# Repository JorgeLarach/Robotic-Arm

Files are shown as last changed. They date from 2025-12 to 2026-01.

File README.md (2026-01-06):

# Robot Arm
Welcome to the readme and devlog for my Robot Arm project! This was about a month long project, done entirely in December 2025. Here you will find the code, pictures, and all the documentation you might need for this personal project. It is a 4-axis robotic arm with a gripper, controlled by an STM32 Nucleo-F401RE microcontroller, a PCA9685 servo driver, and a breadboard power supply module I had laying around. You can find a video of this thing working in the Documentation/Pictures folder. Though I'm leaving this project for now, I do plan on coming back and implementing inverse kinematics control. If you have any questions or need to get in touch, feel free to contact me at jorgelarachesp@gmail.com.

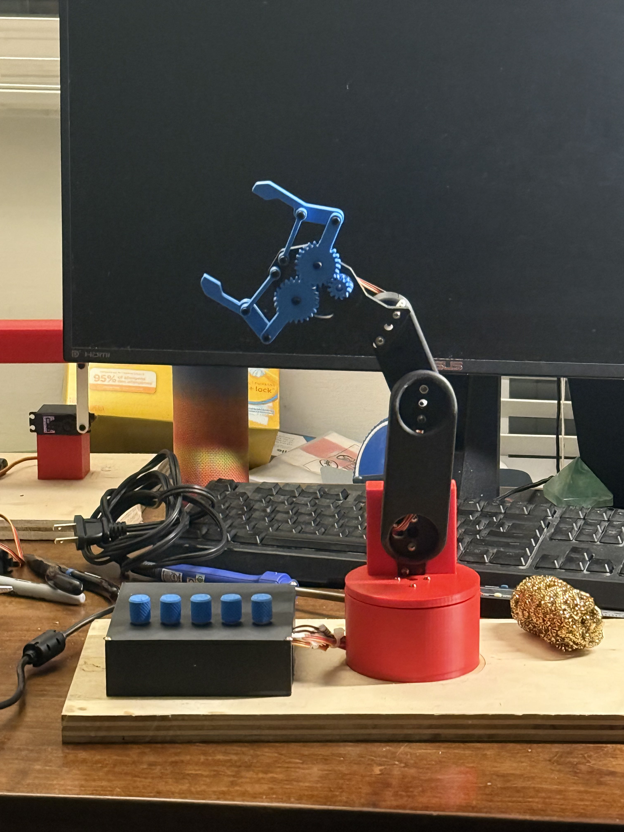
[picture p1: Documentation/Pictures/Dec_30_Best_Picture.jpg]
December 30th best picture

## _Devlog_
### _1/6/2026_:
After I finished the design portion of the robot, I had to come up with a layout and design of the electronics box. I sketched it out on paper, and my original idea was for it to contain:
* the power supply module,
* the STM32 MCU,
* a solder breadboard to supply voltage to the potentiometers, and
* the PCA9685 module.

It wasn't until I modeled it up and printed it that I realized the potentiometers didn't need the breadboard to supply 3.3V and GND to each one, I could just connect the first one to the last 3.3V output on the power supply and daisy chain jumper wires to each subsequent one. I prototyped it out on a solderless breadboard and it worked, so I got to soldering. It was never my strong suit, and I did make a few janky connections that snapped off and had to solder back on later, but it worked! I attached each potentiometer to the lid with some provided nuts and connected their signal wires to the ADC pins on the Nucleo. Unfortunately, this means that you can't remove the lid without disconnecting the signal wires, but I don't mind, since I know exactly where they go. Also there's a big empty space in the box where the solder breadboard would have gone but that's ok. I will admit I made some pretty heinous mistakes with the electronics box design, but its nothing some filing and cutting couldn't fix. 

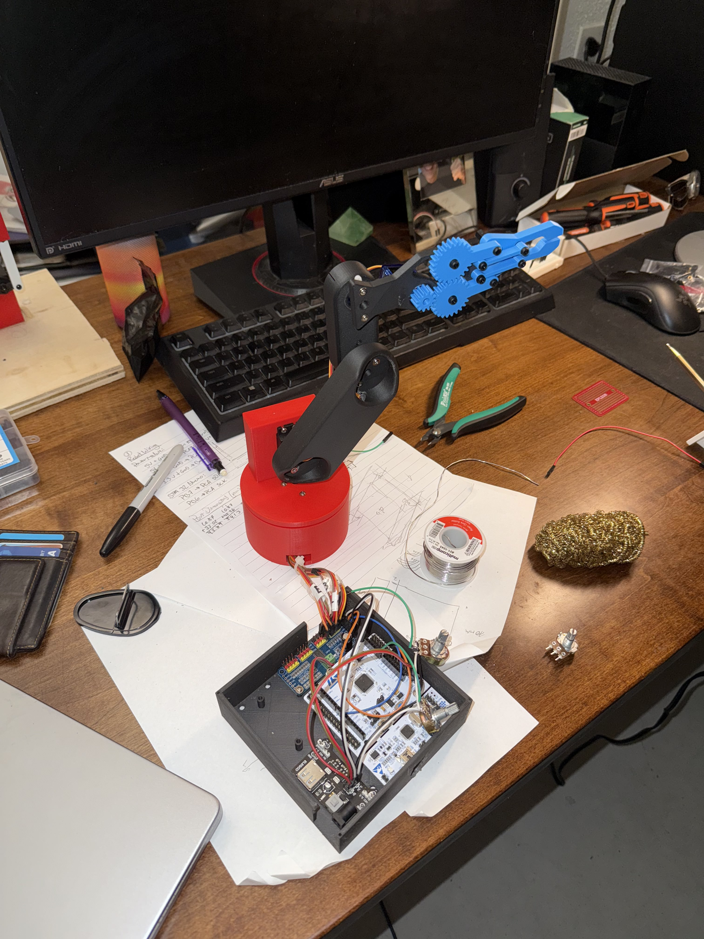
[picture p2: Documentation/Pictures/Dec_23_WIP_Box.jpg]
December 23rd WIP electronics box


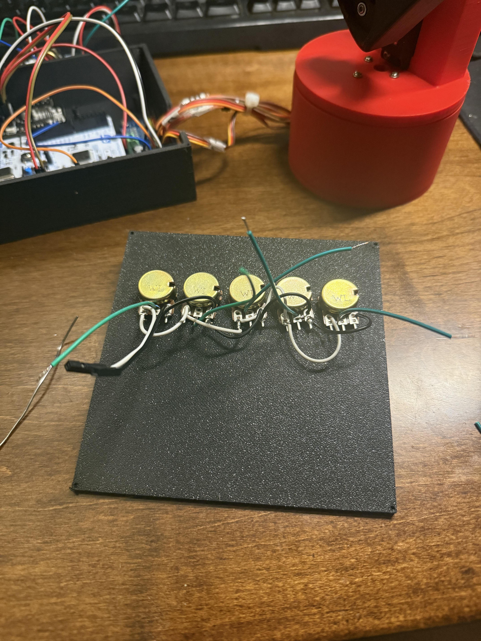
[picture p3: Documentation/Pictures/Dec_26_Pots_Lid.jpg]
December 26th pots on lid


Another big challenge I faced AFTER designing and making the robot was handling multichannel ADC. This completely blindsided me, as I was operating under the understanding that, if it works and its easy with one potentiometer, it'll be easy with more than one. I was dead wrong. This was a much deeper rabbit hole than I ever expected. I'll spare you the gory details, but I ended up using continuously converted DMA accessed ADC values to an ADC array. You can check out the MX_ADC1_Init function in main.c to see more. Once I had that working, I was done with the project on December 30th!
### _12/20/2025_:
The design portion of the project is almost done. I spent a lot of time on Fusion designing and modeling parts, and I was finally able to assemble a working robotic arm today. I used [this](https://www.youtube.com/watch?v=MkABKJTZjVg "Arm reference video") video as a visual reference for the general structure and assembly for my arm, though I included a fifth servo at the tip of the forearm to control the claw angle. I modeled up a claw in Fusion using [this](https://www.youtube.com/watch?v=ZmckF8zYbp0&t=2116s "Fusion claw tutorial") tutorial and modified part of it to fit my arm. All STLs are now included in this repository. The potentiometer and breadboard in the image below are only there for debugging reasons, they won't be there in the final build.

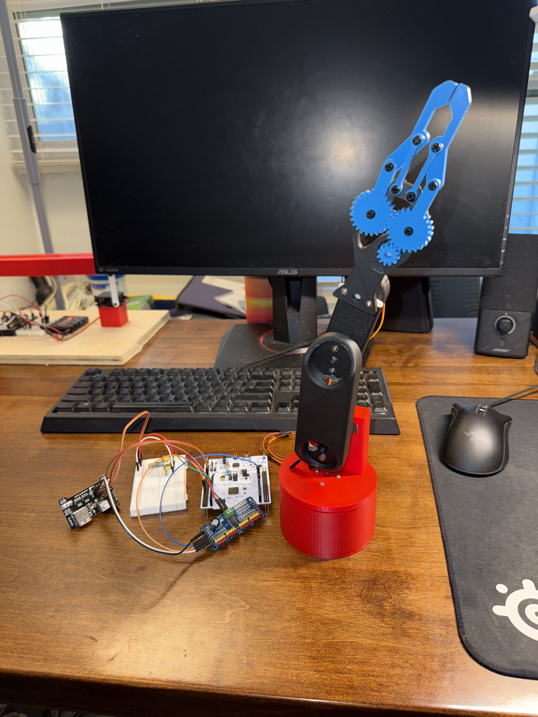
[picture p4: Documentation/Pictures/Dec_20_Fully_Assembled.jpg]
December 20th Fully Assembled


There are five servos: 
* MG996R base servo (provides rotation)
* MG996R lid servo (connects to the arm)
* 2 MG90 forearm servos (one connects to arm, other to control the angle of the claw)
* MG90 claw servo (controls claw mechanism)

Next, I will disassemble the five main pieces of the arm (base, lid, arm, forearm, claw) and individually center each servo at 90 degrees, so there is equal amount of movement on either side available from the centered position. After that, I'll connect extension jumper cables to each MG90 servo (the base and lid servo's wires can reach the PCA9685 no problem) and label each end to their respective servo's funcion. I'll also make an attempt to hide the servo wires as best I can; I included some cable holes in the design but I'm not sure whether they'll actually be all that helpful. After that, I have three more tasks to tackle:
* Build enclosure for electronics (breadboard power supply circuit, MCU, PCA9685)
* Start programming an inverse kinematics driver
* Start designing a smaller, potentiometer driven controller arm (alternative would be to put five potentiometers in the electronics enclosure to control each servo individually)

Below are some pictures of the design process from this past week:

December 17: Working base and lid
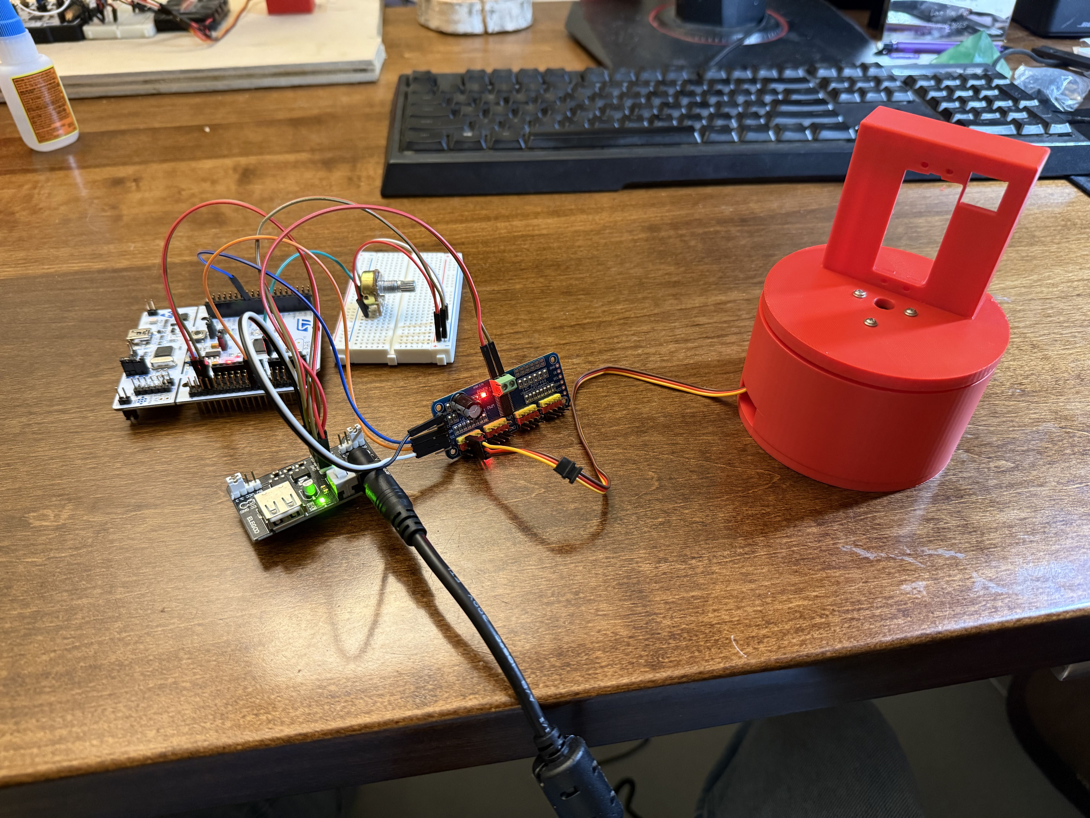
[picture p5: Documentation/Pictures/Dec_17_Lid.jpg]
December 17th Lid


December 18: Arm assembled

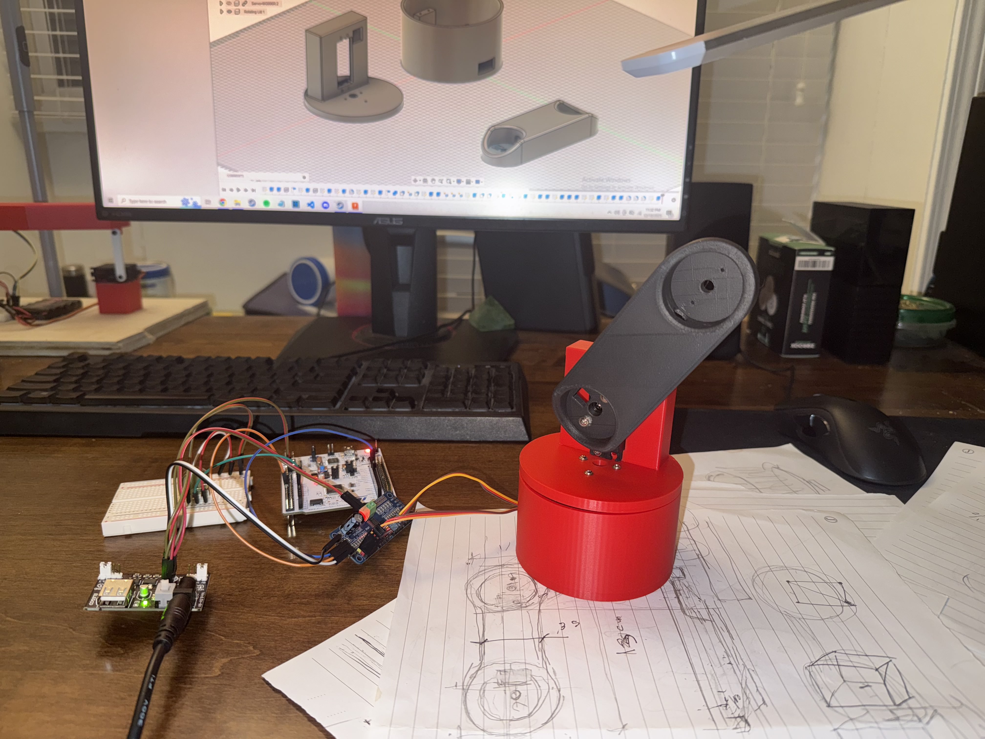
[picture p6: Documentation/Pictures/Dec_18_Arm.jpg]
December 18th Arm


### _12/10/2025_:
Just finished a working early version of the PCA9685 driver. Using STM's I2C HAL interface to read/write, doing PWM calculations, and getting a servo to oscillate. Got some help online on how to do this, namely from [here](https://www.micropeta.com/video113 "Helpful link") and a number of YouTube videos. Thoroughly annotated the code so its mechanisms are clear and easy to understand. I think at this point I'm ready to start the dreaded design section of this project, but I'm at a crossroads. I saw a really cool [video](https://www.youtube.com/watch?v=5toNqaGsGYs "Helpful link") where a smaller robotic arm "controller" was made with potentiometers, which then controlled the positions of the main robot's servos. I thought this idea was so cool and I really want to give it a shot, so I think my next goal will be to continue to procrastinate the Fusion section of this project and to write a simple ADC interface to control the position of just one servo with one potentiometer. I was also thinking about having multiple "modes" for the arm, where it is controlled by the little controller arm in one mode and maybe controlled with some kind of inverse kinematics algorithm in another mode, but as of today I really have no idea how that could work. I want this project to be a little more software heavy than my last two, so I might spend more time looking into this inverse kinematics idea.

### _12/09/2025_:
Since I finished my Ball and Beam project last month, I've been researching and preparing for this new project, the Robotic Arm. Because it uses multiple servos, I figured a PCA9685 I2C controller would be appropriate for this use-case. I also chose to continue to use the STM32 Nucleo line of microcontrollers. For the electronics and wiring section of this project, I had three goals:
* I wanted to make a project that doesn't rely on battery for voltage. It was kind of inconvenient and wanted to try out using a wall powered DC power supply instead.
* I wanted to power the microcontroller externally, rather than supplying USB power, which is what I had done in my previous projects.
* I wanted to challenge myself to not use breadboards at all; something I had relied on previously.

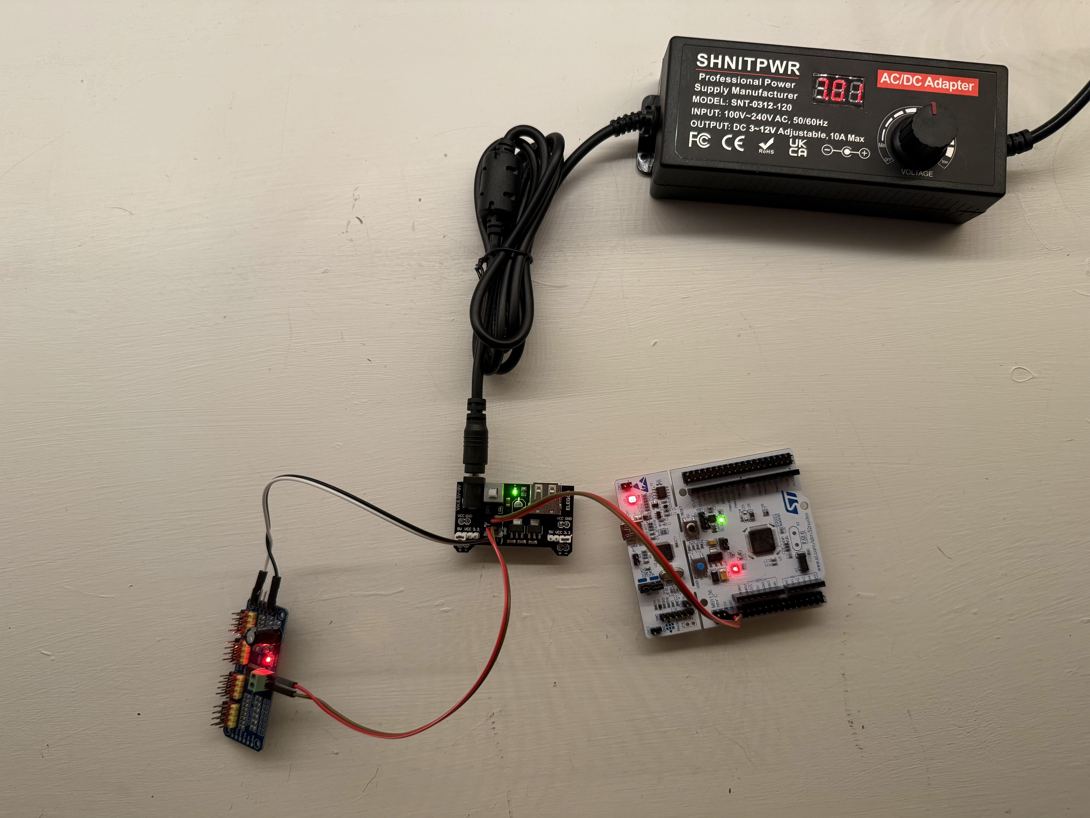
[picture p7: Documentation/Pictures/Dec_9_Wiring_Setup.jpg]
December 9th Wiring Setup


As of today, I've taken care of the EV5 (5V) for the Nucleo, the V+ (5V) for the PCA9685, and the Vcc (3.3V) for the PCA9685, all using a 3-12V adjustable DC power supply and an Elegoo Breadboard Power Supply module I found lying around. So far, it looks like I'm within spec for all these components. Next, I'll start working on the I2C driver to control just a single servo motor.

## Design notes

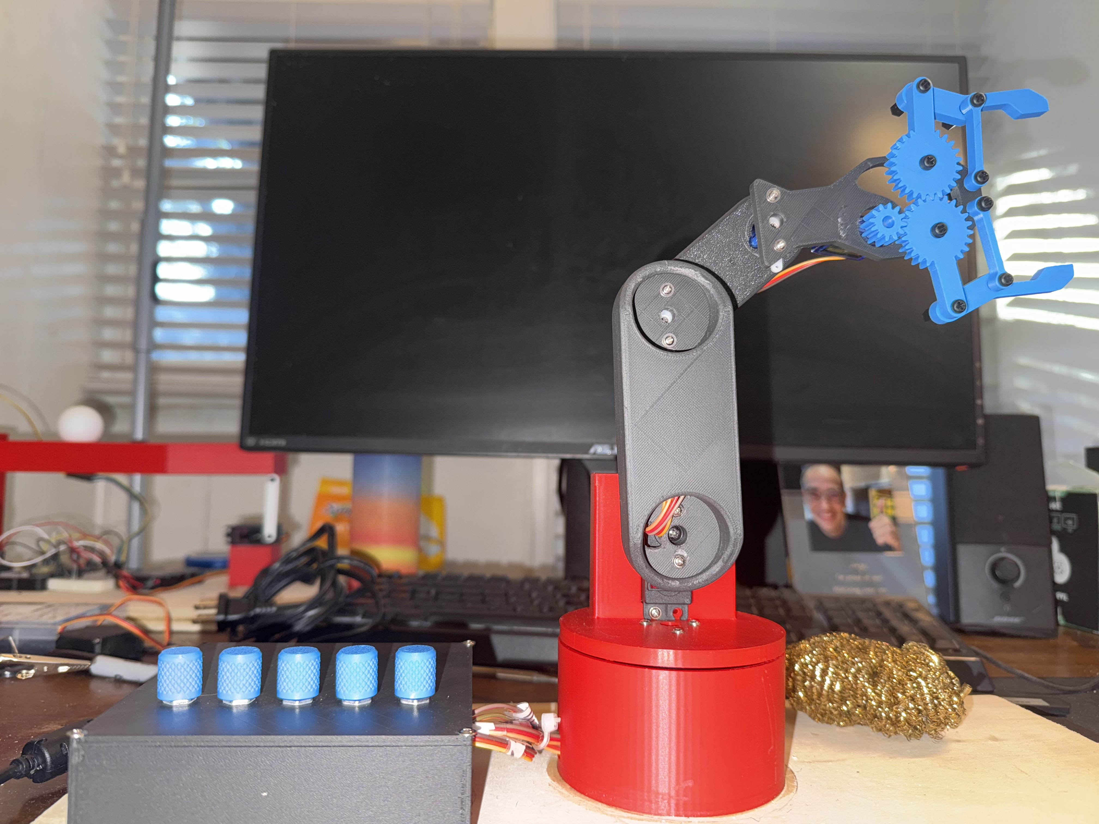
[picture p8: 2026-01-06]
Documentation/Pictures/Dec_30_Full_Robot.jpg

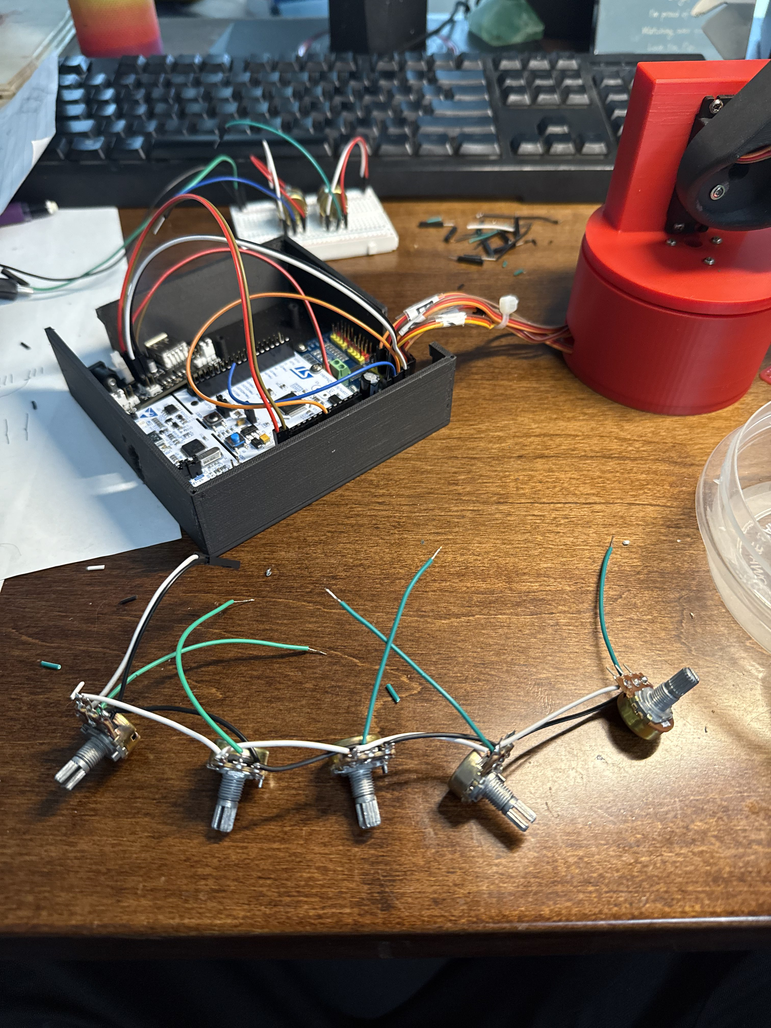
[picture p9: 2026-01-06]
Documentation/Pictures/Dec_26_WIP_Pots.jpg

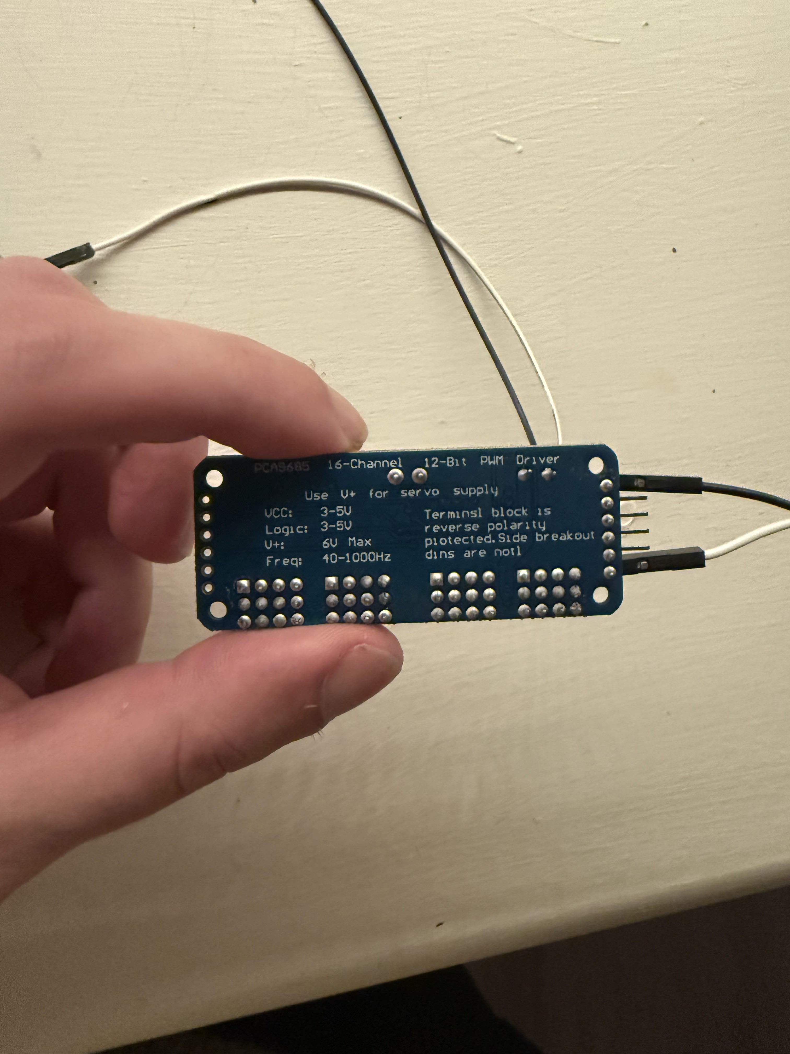
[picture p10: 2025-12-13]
Documentation/Pictures/PCA9685 Reverse Side.jpg

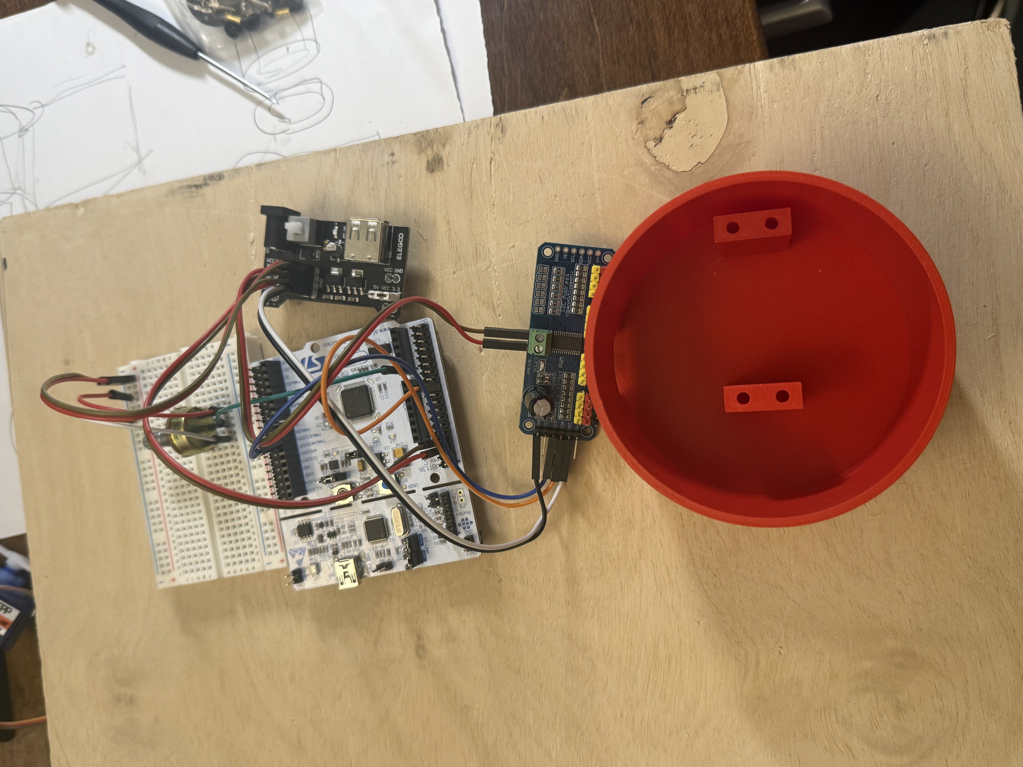
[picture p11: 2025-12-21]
Documentation/Pictures/Dec_16_Base.jpg

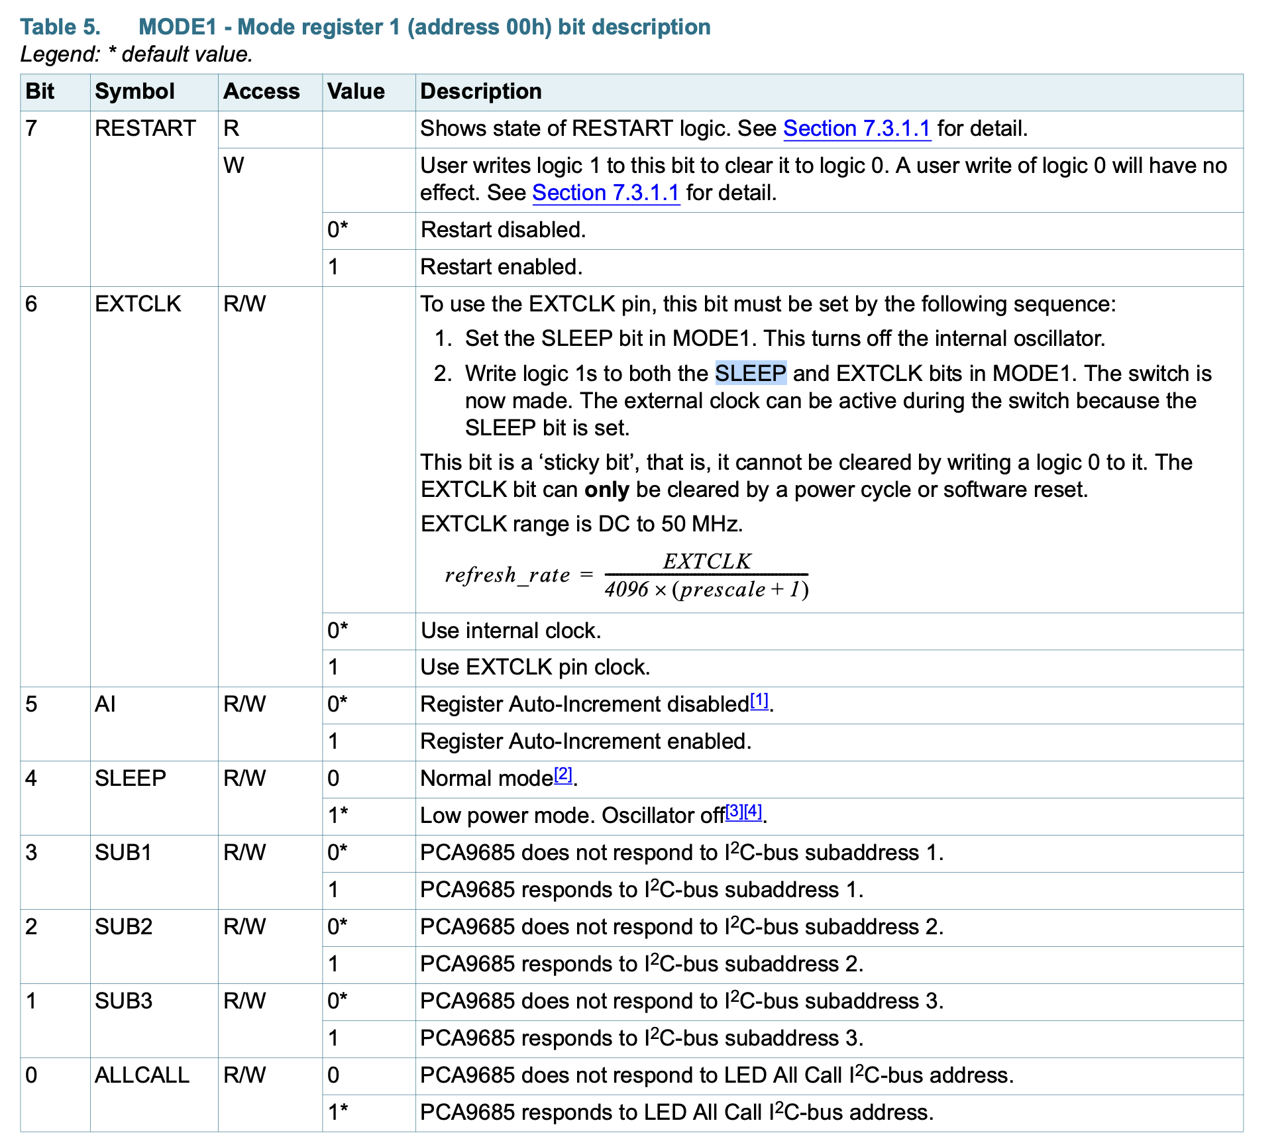
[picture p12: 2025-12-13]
Documentation/Pictures/PCA9685 MODE1 Register Address.png

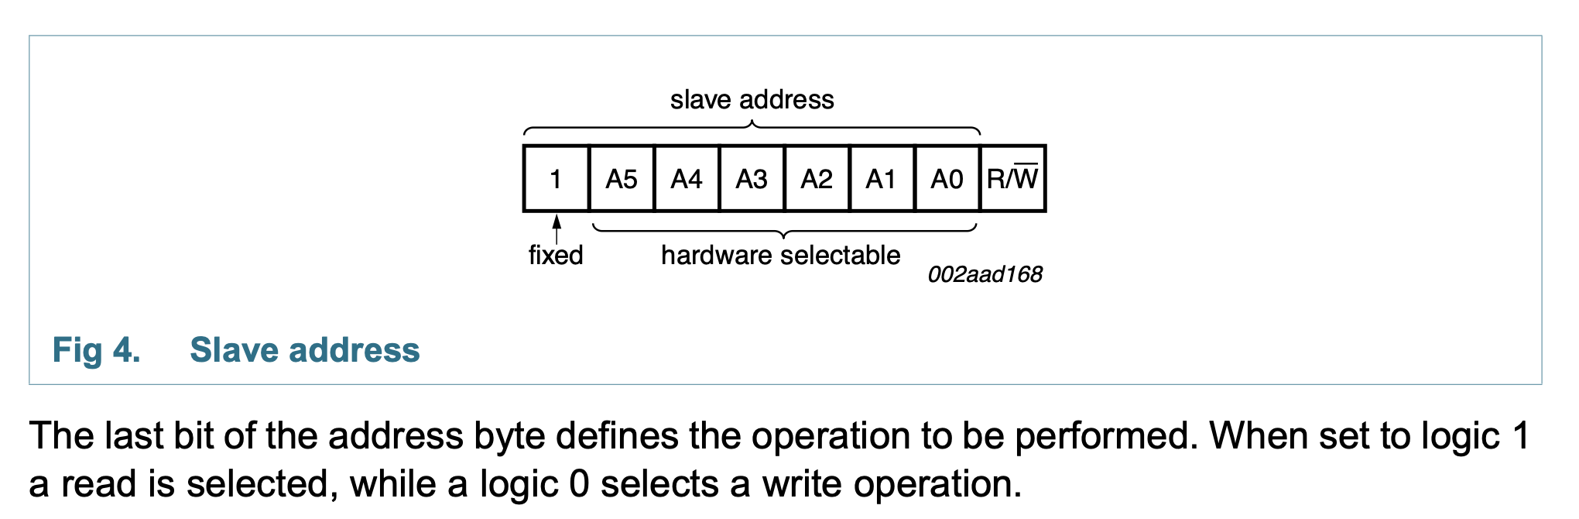
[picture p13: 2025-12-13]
Documentation/Pictures/PCA9685 Slave Address.png

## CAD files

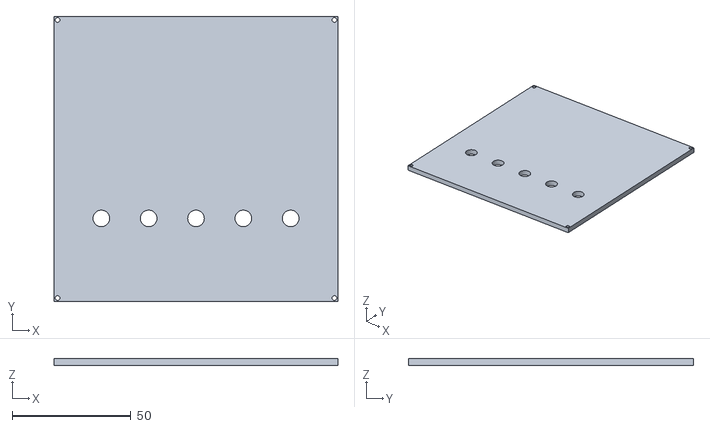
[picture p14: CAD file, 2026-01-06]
Documentation/3D Print STLs/Electronics Box Lid v1.1.stl
119.5 x 120.0 x 3.00

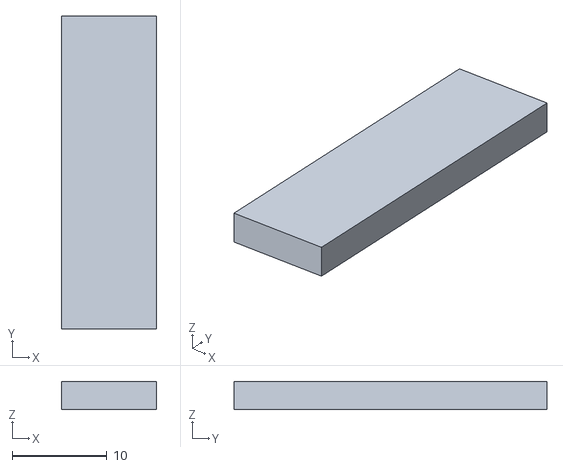
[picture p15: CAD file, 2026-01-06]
Documentation/3D Print STLs/Wire Clip Arm v1.stl
10.0 x 33.0 x 3.00

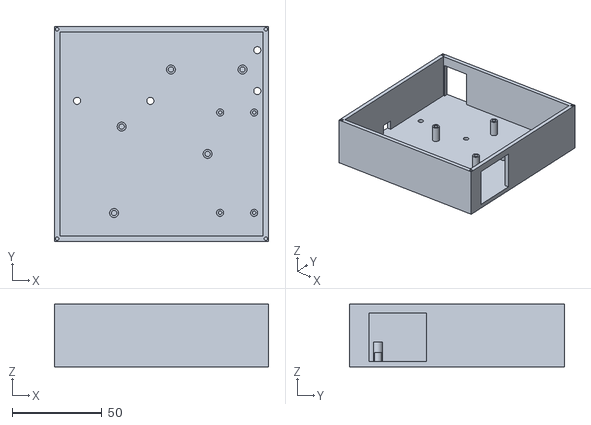
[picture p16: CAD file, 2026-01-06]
Documentation/3D Print STLs/Electronics Box Body.stl
119.5 x 120.0 x 35.0

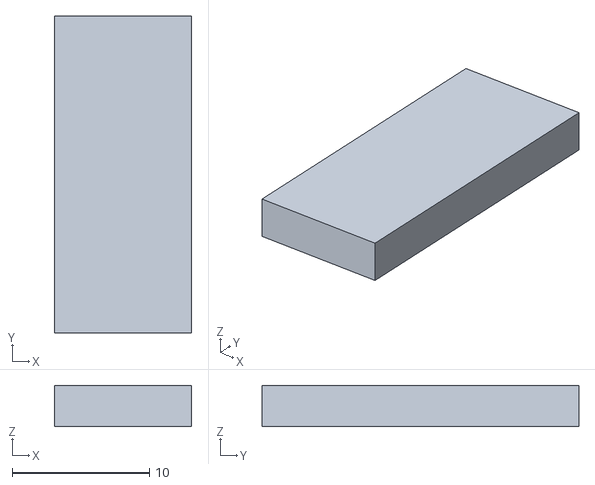
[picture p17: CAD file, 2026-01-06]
Documentation/3D Print STLs/Wire Clip Forearm v1.stl
10.0 x 23.1 x 3.00

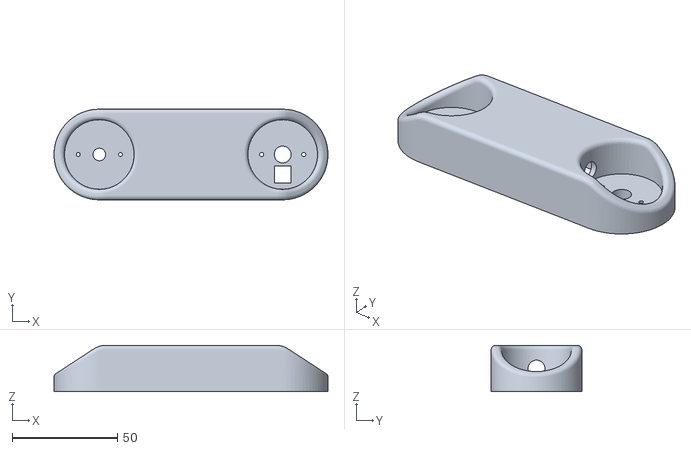
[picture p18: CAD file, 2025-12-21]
Documentation/3D Print STLs/Arm v1.1.stl
130.0 x 43.0 x 22.0

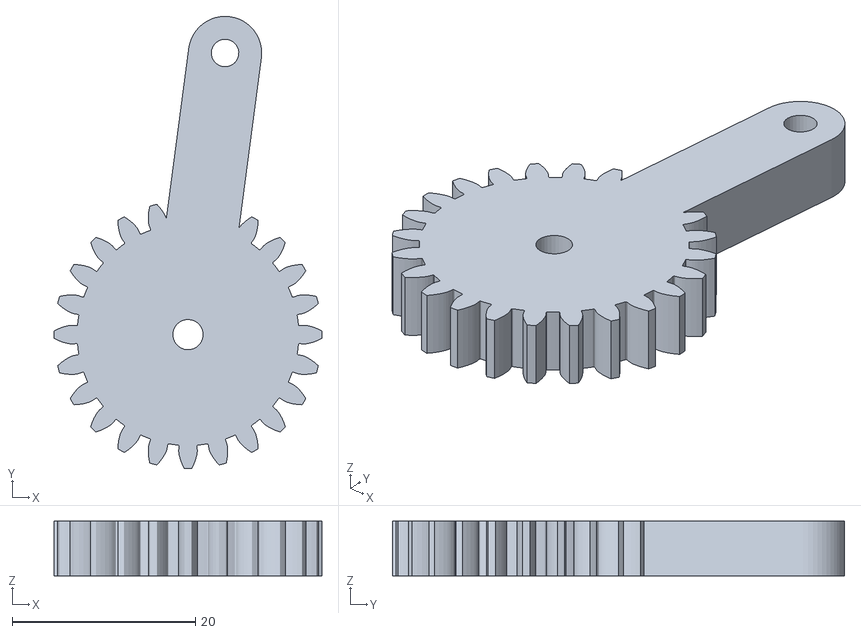
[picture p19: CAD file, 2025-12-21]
Documentation/3D Print STLs/Gripper Connector Gear 2 v1.0.stl
29.2 x 49.4 x 6.00

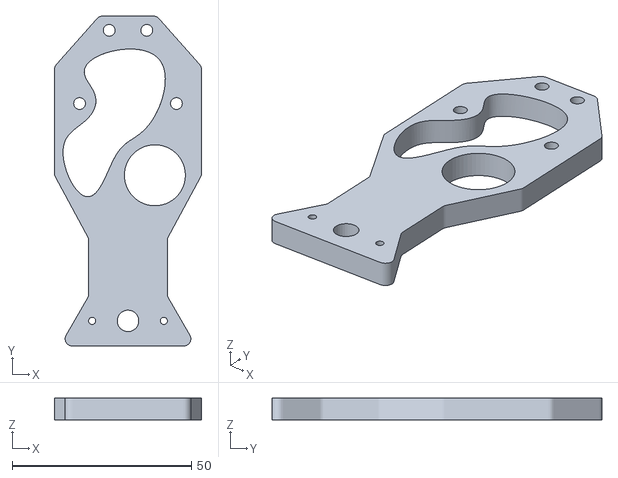
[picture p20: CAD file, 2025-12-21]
Documentation/3D Print STLs/Gripper Base v1.2.stl
41.0 x 92.0 x 6.00

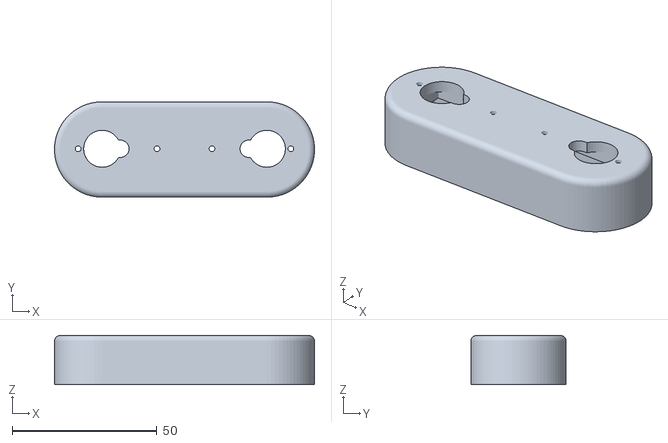
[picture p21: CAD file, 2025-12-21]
Documentation/3D Print STLs/Forearm v1.1.stl
90.0 x 33.0 x 17.0

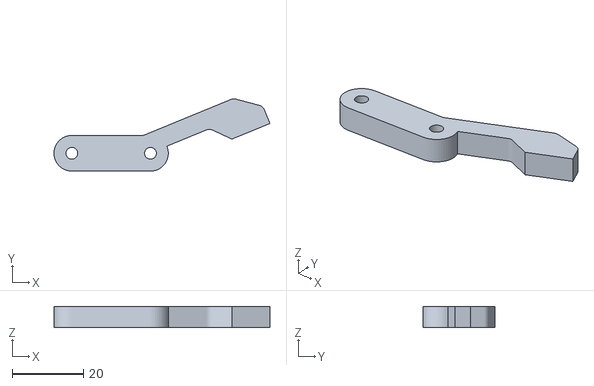
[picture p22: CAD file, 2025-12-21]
Documentation/3D Print STLs/Gripper Claw v1.0.stl
60.4 x 20.2 x 6.00

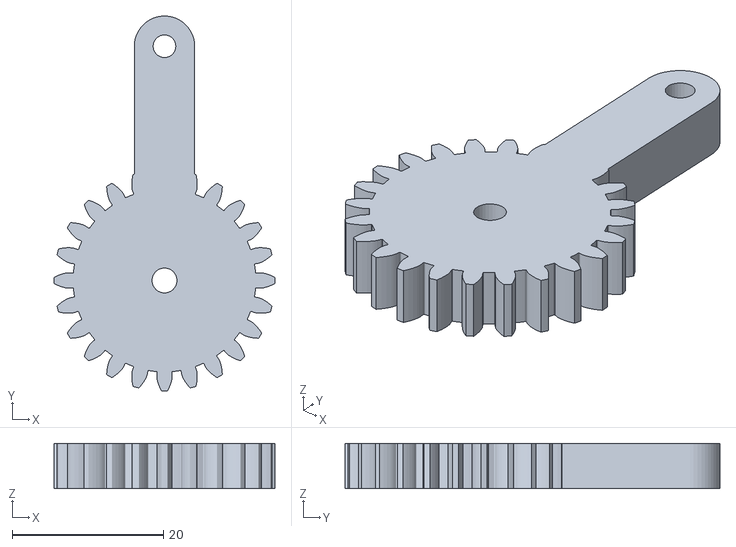
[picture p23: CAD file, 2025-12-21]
Documentation/3D Print STLs/Gripper Connector Gear v1.0.stl
29.2 x 49.6 x 6.00

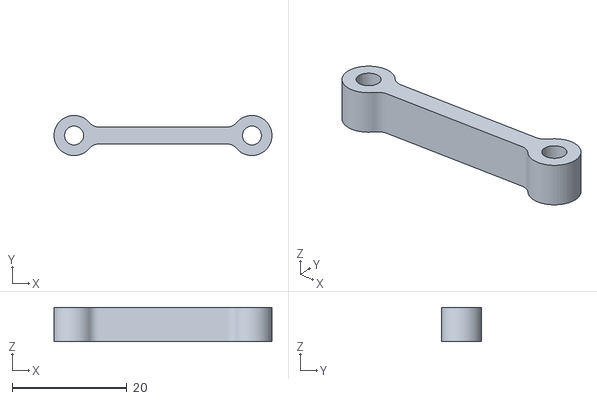
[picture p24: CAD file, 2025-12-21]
Documentation/3D Print STLs/Gripper Connector v1.0.stl
38.0 x 6.99 x 6.00

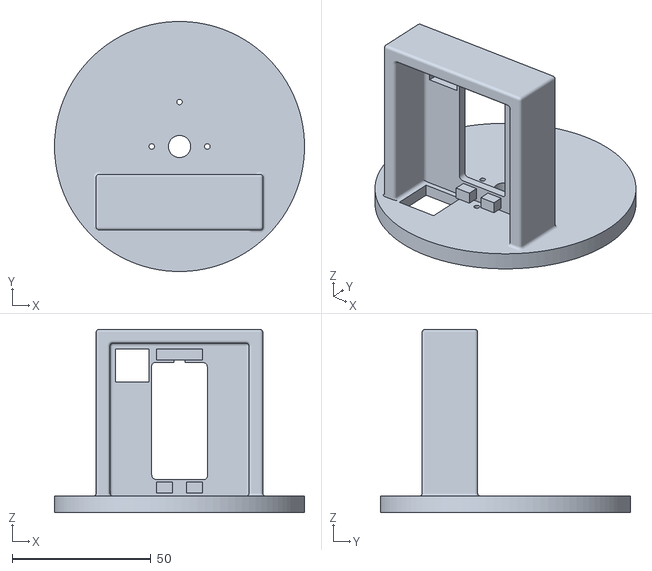
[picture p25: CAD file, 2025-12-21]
Documentation/3D Print STLs/Rotating Lid v1.2.stl
90.0 x 90.0 x 66.0

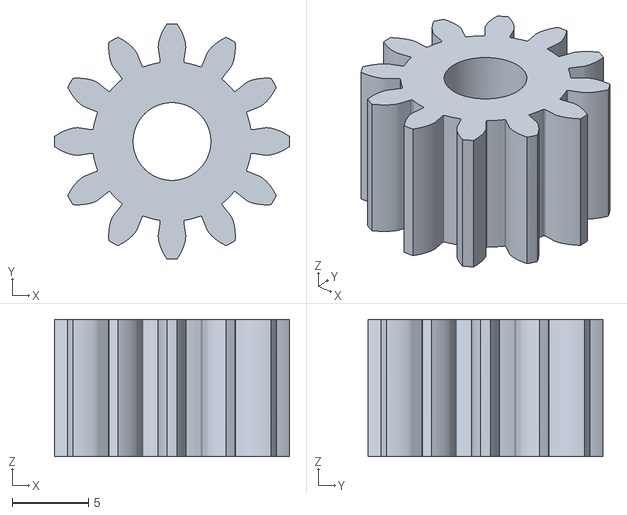
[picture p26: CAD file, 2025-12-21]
Documentation/3D Print STLs/Gripper Servo Gear v1.0.stl
15.4 x 15.4 x 9.00

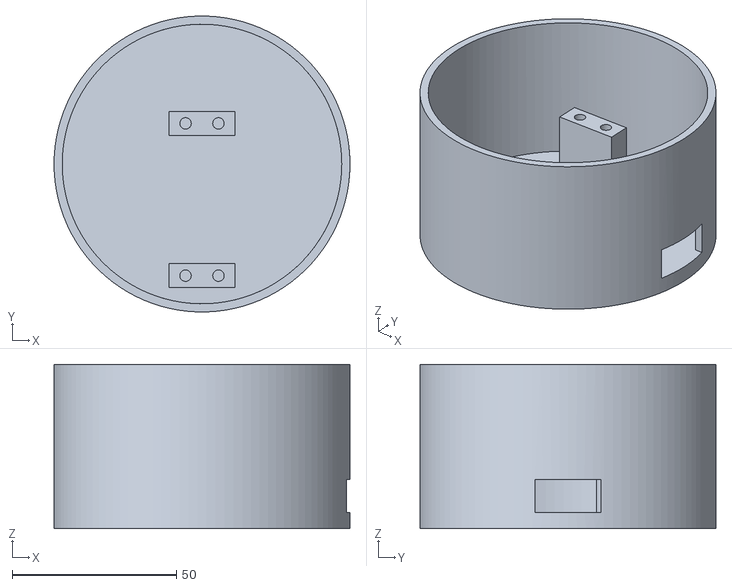
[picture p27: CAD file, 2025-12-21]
Documentation/3D Print STLs/Base v1.1.stl
90.0 x 90.0 x 50.0

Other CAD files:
Documentation/3D Print STLs/Old STLs/Rotating Lid v1.0.stl
Documentation/3D Print STLs/Old STLs/Rotating Lid v1.1.stl
Documentation/3D Print STLs/Old STLs/Gripper Base v1.0.stl
Documentation/3D Print STLs/Electronics Box Lid v1.stl
Documentation/3D Print STLs/Arm v1.0.stl
Documentation/3D Print STLs/Imported Models/Servo+MG996R.f3d
Documentation/3D Print STLs/Old STLs/Base v1.0.stl
Documentation/3D Print STLs/Old STLs/Forearm v1.0.stl
Documentation/3D Print STLs/Old STLs/Gripper Base v1.1.stl

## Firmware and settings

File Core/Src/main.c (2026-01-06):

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
/* Includes ------------------------------------------------------------------*/
#include "main.h"

/* USER CODE BEGIN Includes */
#include <stdio.h>
#include <string.h>
/* USER CODE END Includes */

ADC_HandleTypeDef hadc1;
DMA_HandleTypeDef hdma_adc1;

I2C_HandleTypeDef hi2c1;

UART_HandleTypeDef huart2;

/* USER CODE BEGIN PV */

#define NUM_OF_SERVOS 5

const uint8_t adc_index[NUM_OF_SERVOS] = { 0, 2, 4, 6, 8 };
uint16_t ADC_buffer[NUM_OF_SERVOS * 2];
uint8_t servo_angles[NUM_OF_SERVOS];

char message[40] = {'\0'};

/* USER CODE END PV */

void SystemClock_Config(void);
static void MX_GPIO_Init(void);
static void MX_DMA_Init(void);
static void MX_USART2_UART_Init(void);
static void MX_I2C1_Init(void);
static void MX_ADC1_Init(void);
/* USER CODE BEGIN PFP */
void PCA9685_set_bit(uint8_t reg, uint8_t bit, uint8_t val);
void PCA9685_set_pwm_freq(uint16_t freq);
void PCA9685_init(uint16_t freq);
void PCA9685_set_pwm(uint8_t servo, uint16_t on_time, uint16_t off_time);
void PCA9685_set_servo_angle(uint8_t servo, float angle);
void update_servos(void);
/* USER CODE END PFP */

/* USER CODE BEGIN 0 */

// PCA9865 Core Constants
#define PCA9685_OSC_CLOCK 25000000 // 25MHz internal clock
#define PCA9685_PWM_RESOLUTION 4096 // 12 bit PWM internal resolution
#define PCA9685_MIN_PWM 102.4 // 0.5ms
#define PCA9685_MAX_PWM 512 // 2.5ms

// PCA9685 Addresses
#define PCA9685_ADDRESS   (0x40 << 1)  // 0x40 (100 0000) in datasheet, but lshifted because HAL uses 8 bits internally for r/w bit
#define PCA9685_MODE1     0x00 // Using MODE1, sounds like it works the way I want it to
#define PCA9685_PRESCALE  0xFE // Register address for the prescaler that sets PWM frequency
#define PCA9685_PWM0_ON_L 0x06 // Location of first 8 bits of PWM0 register (out of 12 - leaving those blank)

// MODE1 (8 bits) Register Control Bits
#define PCA9685_MODE1_SLEEP_BIT   4 // Bit 4 of MODE1
#define PCA9685_MODE1_AI_BIT      5 // Auto Increment Bit
#define PCA9685_MODE1_RESTART_BIT 7 // Restart Bit

/* @brief for I2C Mem Read and Write
 * hi2c:       Pointer to a I2C_HandleTypeDef structure that contains the configuration information for the specified I2C.
 * DevAddress: Target device address - The device 7 bits address value in datasheet must be shifted to the left before calling the interface
 * MemAddress: Internal memory address
 * MemAddSize: Size of internal memory address
 * pData:      Pointer to data buffer
 * Size:       Amount of data to be sent
 * Timeout:    Timeout duration in ms */
void PCA9685_set_bit(uint8_t reg, uint8_t bit, uint8_t val){
	uint8_t register_value;
	HAL_I2C_Mem_Read(&hi2c1, PCA9685_ADDRESS, reg, 1, &register_value, 1, 10);  // Read current value of specified reg into register_value
	register_value = ((register_value & ~(1 << bit)) | (val << bit));             // Clear specified bit, then or with val (=val)
	HAL_I2C_Mem_Write(&hi2c1, PCA9685_ADDRESS, reg, 1, &register_value, 1, 10); // Write modified register to PCA9685
	HAL_Delay(1); // Time to process the write
}

/* @brief for setting PWM frequency
 * This function calculates and writes a prescale value to the PCA9685 given
 * A desired frequency value
 * Internal oscillator clock speed
 * Internal pwm resolution */
void PCA9685_set_pwm_freq(uint16_t freq){ // 12-bit PWM, so freq represented in 16 bits
	uint8_t prescale;
	if(freq >= 1526) prescale = 0x03;
	else if (freq <= 24) prescale = 0xFF;
	prescale = (PCA9685_OSC_CLOCK/(PCA9685_PWM_RESOLUTION * freq));
	PCA9685_set_bit(PCA9685_MODE1, PCA9685_MODE1_SLEEP_BIT, 1);
	HAL_I2C_Mem_Write(&hi2c1, PCA9685_ADDRESS, PCA9685_PRESCALE, 1, &prescale, 1, 10);
	PCA9685_set_bit(PCA9685_MODE1, PCA9685_MODE1_SLEEP_BIT, 0);
	PCA9685_set_bit(PCA9685_MODE1, PCA9685_MODE1_RESTART_BIT, 1);
}

/* @brief for initializing PCA9685
 * This function sets the PWM frequency for the PCA9685 and sets the Auto-Increment Bit in MODE1
 * AI = 1 allows for writing to multiple bytes stored contiguously in PCA9685's internal memory, see set_pwm function */
void PCA9685_init(uint16_t freq){
	PCA9685_set_pwm_freq(freq);
	PCA9685_set_bit(PCA9685_MODE1, PCA9685_MODE1_AI_BIT, 1);
}

/* @brief for selecting servo and setting PWM
 * Each LED (servo) has 4 bytes for PWM
 * ON_L, ON_H, OFF_L, OFF_H
 * Masking and shifting on_time and off_time into respective locations in array
 * on_time will always be 0, so period always begins with high pulse
 * MODE1 bit 5 (AI) allows for contiguous memory writing */
void PCA9685_set_pwm(uint8_t servo, uint16_t on_time, uint16_t off_time){
	uint8_t pwm[4];
	uint8_t reg_address = PCA9685_PWM0_ON_L + (4 * servo);
	pwm[0] = on_time & 0xFF;
	pwm[1] = on_time >> 8;
	pwm[2] = off_time & 0xFF;
	pwm[3] = off_time >> 8;
	HAL_I2C_Mem_Write(&hi2c1, PCA9685_ADDRESS, reg_address, 1, pwm, 4, 10);
}

/* @brief for setting servo angle
 * Linear mapping from 0-180 degrees to to PWM.
 * Converts angle to pulse width between PCA9685_MIN_PWM and MAX_PWM
 * and writes it to the specified PCA9685 channel. */
void PCA9685_set_servo_angle(uint8_t servo, float angle){
	float val = PCA9685_MIN_PWM + (angle / 180.0f) * (PCA9685_MAX_PWM - PCA9685_MIN_PWM);
	PCA9685_set_pwm(servo, 0, (uint16_t)val);
}

/* @brief for converting ADC values
 * Converts 12-bit ADC value into an angle value (0-180) */
uint8_t ADC_to_angle(uint16_t potentiometer){
	uint8_t angle = (potentiometer * 180)/4095;
	if(angle > 180) angle = 180;
	return angle;
}

/* @brief for updating servos
 * Loops through continuous DMA-written ADC buffer (with offset indices)
 * and converts values to angles, then updates corresponding servo angle */
void update_servos(void){
	for (uint8_t i = 0; i < NUM_OF_SERVOS; i++) {
		uint16_t pot = ADC_buffer[adc_index[i]];
	    servo_angles[i] = ADC_to_angle(pot);
	    PCA9685_set_servo_angle(i, servo_angles[i]);
	}
}

/* USER CODE END 0 */

/**
  * @brief  The application entry point.
  * @retval int
  */
int main(void)
{

  /* MCU Configuration--------------------------------------------------------*/

  /* Reset of all peripherals, Initializes the Flash interface and the Systick. */
  HAL_Init();

  /* Configure the system clock */
  SystemClock_Config();

  /* Initialize all configured peripherals */
  MX_GPIO_Init();
  MX_DMA_Init();
  MX_USART2_UART_Init();
  MX_I2C1_Init();
  MX_ADC1_Init();
  /* USER CODE BEGIN 2 */

  PCA9685_init(50); // Servos require 50hz frequency
  HAL_ADC_Start_DMA(&hadc1, (uint32_t*)ADC_buffer, NUM_OF_SERVOS);

  /* USER CODE END 2 */

  /* Infinite loop */
  /* USER CODE BEGIN WHILE */

  while (1)
  {
    /* USER CODE END WHILE */

    /* USER CODE BEGIN 3 */
	  update_servos();
	  HAL_Delay(100);
  }
  /* USER CODE END 3 */
}

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


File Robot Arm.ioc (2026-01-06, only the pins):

Mcu.UserName=STM32F401RETx
PA0-WKUP.Signal=ADCx_IN0
PA1.Signal=ADCx_IN1
PA13.GPIO_Label=TMS
PA13.Signal=SYS_JTMS-SWDIO
PA14.GPIO_Label=TCK
PA14.Signal=SYS_JTCK-SWCLK
PA2.GPIO_Label=USART_TX
PA2.Signal=USART2_TX
PA3.GPIO_Label=USART_RX
PA3.Signal=USART2_RX
PA4.Signal=ADCx_IN4
PA5.GPIO_Label=LD2 [Green Led]
PA5.Signal=GPIO_Output
PB0.Signal=ADCx_IN8
PB3.GPIO_Label=SWO
PB3.Signal=SYS_JTDO-SWO
PB6.Signal=I2C1_SCL
PB7.Signal=I2C1_SDA
PC1.Signal=ADCx_IN11
PC13-ANTI_TAMP.GPIO_Label=B1 [Blue PushButton]
PC13-ANTI_TAMP.Signal=GPXTI13
PC14-OSC32_IN.Signal=RCC_OSC32_IN
PC15-OSC32_OUT.Signal=RCC_OSC32_OUT

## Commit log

2025-12-10 completed initial wiring setup. uploaded picture
2025-12-10 First devlog for project
    Document project goals and initial setup for Robotic Arm.
2025-12-11 finished early version of pca9685 driver, nothing is broken so far
    [Robot Arm.ioc, main.c]
2025-12-21 nearly finished arm design, included STLs and pictures, added ADC driver for servo debugging and assembly
    [Arm v1.0.stl, Arm v1.1.stl, Base v1.0.stl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]
2025-12-24 starting work on configuring ADC to get readings from five potentiometers
2026-01-06 adding final pictures
    [Electronics Box Body.stl, Electronics Box Lid v1.1.stl, Electronics Box Lid v1.stl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]

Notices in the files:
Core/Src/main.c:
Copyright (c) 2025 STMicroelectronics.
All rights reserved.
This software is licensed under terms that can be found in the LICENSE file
